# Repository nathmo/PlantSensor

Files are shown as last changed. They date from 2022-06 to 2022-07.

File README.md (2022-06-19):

# PlantSensor
Sensors node to monitor ambient light, temperature, humitidy, noise and soil moisture.
It it also able to drive a water pump and two light and have a LoRa transceiver to hopefully prevent my house plants from dying (among other use)
it was designed with a few use case in mind : indoor plant, outdoor plant, weather station, mailbox notifier, environemental sensor (3 I2C port that can be used for with sensors @ 3V3)
it is low power (when en deepsleep) (current draw under 50 uA@3V7 and even less at 12V)

## Features
- 3 I2C port for 3V3 peripheral (designed for OLED display, lux meter, pressure sensors)
- ambiant humidity sensors and temperature (DHT11)
- soil humidity sensors (capacitive module with analog out)
- lux meter
- pressure sensor
- microhone (detect noise level + weather / rain / wind ?)
- 3 mosftet output, max 6A total accross 3 mosfet at any time
- low power features, turn off every peripheral except ESP32 that can deepsleep and LoRa
- LoRa (433Mhz) (not compatible with TTN :( 868 Mhz is too expensive) , wifi and bluetooth connectivity
- buzzer to locate the sensors (and maybe repell some animal ?)
- GPS to track the sensors and have an accurate time base
- local data display on OLED screen or remote via the LoRa
- input voltage monitoring, get an idea of the battery left if powered by one

PCBB
PCBA

the PCB is 70 mm * 70 mm, i will add a better fixation system

## content
kicad schematic
BOM (20-40 CHF per unit, aliexpress as sole suplier (except PCB itself)

## futur works
- assemble and test the PCB once its manufactured
- write code to use it
- check current of the buck converter in low power mode

## firmware 
whenever the CPU come out of the sleep mode one of the following action should be performed :

mode 1)
read the config
read the sensors specified in the config
take the decision to turn on or off the mosfet if the condition set in the config are set
take the decision to display the data as specified in the config
send the data to a server if set in the config
retreive config update from the server if any and update own config or pass it to the next node

mode 2)
just transmit to any exit node the data passed uppon
applie the insctruction if we are the destination node

comming out of sleep mode are set in the config
- button action
- timer
- LoRa event

which system they trigger should also be specified in the config

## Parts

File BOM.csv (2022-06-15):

screw terminal | https://fr.aliexpress.com/item/4000290521933.html
mosfet | https://fr.aliexpress.com/item/32902232749.html
buck | https://fr.aliexpress.com/item/4000714041437.html
buzzer | https://fr.aliexpress.com/item/32857436073.html
microphone | https://fr.aliexpress.com/item/4000964400783.html
luxmeter | https://fr.aliexpress.com/item/32859303675.html
pressure | https://fr.aliexpress.com/item/1005001827073707.html
switch | https://fr.aliexpress.com/item/1005001291454145.html
LoRa 433 | https://fr.aliexpress.com/item/1005003451087717.html
GPS | https://fr.aliexpress.com/item/1005001704030454.html
screen | https://fr.aliexpress.com/item/32777216785.html
ESP32 | https://fr.aliexpress.com/item/32813525150.html
soil moisture | https://fr.aliexpress.com/item/32908693444.html
air moisture | https://fr.aliexpress.com/item/1005003157663107.html
DIODE | https://fr.aliexpress.com/item/1005003367932203.html

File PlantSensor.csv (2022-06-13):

Source: | /home/nathann/OneDrive/Documents/Projet/electronic/PlantSensor/PlantSensor/PlantSensor.kicad_sch
Date: | lun 13 jun 2022 01:12:29
Tool: | Eeschema 6.0.2+dfsg-1
Generator: | /usr/share/kicad/plugins/bom_csv_grouped_by_value.py
Component Count: | 51
Individual Components:
Item | Qty | Reference(s) | Value | LibPart | Footprint | Datasheet | MPN | SKU
 |  | BZ1 | Buzzer | Device:Buzzer | Buzzer_Beeper:Buzzer_12x9.5RM7.6 | ~
 |  | C1 | 10uF | Device:C | Capacitor_SMD:C_1206_3216Metric | ~
 |  | C2 | 10uF | Device:C | Capacitor_SMD:C_1206_3216Metric | ~
 |  | C3 | 100nF | Device:C | Capacitor_SMD:C_1206_3216Metric | ~
 |  | C4 | 10uF | Device:C | Capacitor_SMD:C_1206_3216Metric | ~
 |  | C5 | 10uF | Device:C | Capacitor_SMD:C_1206_3216Metric | ~
 |  | C6 | 10uF | Device:C | Capacitor_SMD:C_1206_3216Metric | ~
 |  | C7 | 100nF | Device:C | Capacitor_SMD:C_1206_3216Metric | ~
 |  | C8 | 100nF | Device:C | Capacitor_SMD:C_1206_3216Metric | ~
 |  | C9 | 100nF | Device:C | Capacitor_SMD:C_1206_3216Metric | ~
 |  | C10 | 100nF | Device:C | Capacitor_SMD:C_1206_3216Metric | ~
 |  | C11 | 100nF | Device:C | Capacitor_SMD:C_1206_3216Metric | ~
 |  | C12 | 100nF | Device:C | Capacitor_SMD:C_1206_3216Metric | ~
 |  | C13 | 100nF | Device:C | Capacitor_SMD:C_1206_3216Metric | ~
 |  | C14 | 100nF | Device:C | Capacitor_SMD:C_1206_3216Metric | ~
 |  | J1 | SCREW-TERMINAL-GREEN_2P-5.0_ | OPL_Connector:SCREW-TERMINAL-GREEN_2P-5.0_ | OPL_Connector:H2-5.0-10.5X8.0MM |  |  | 320110031
 |  | J2 | SCREW-TERMINAL-GREEN_2P-5.0_ | OPL_Connector:SCREW-TERMINAL-GREEN_2P-5.0_ | OPL_Connector:H2-5.0-10.5X8.0MM |  |  | 320110031
 |  | J3 | SCREW-TERMINAL-GREEN_2P-5.0_ | OPL_Connector:SCREW-TERMINAL-GREEN_2P-5.0_ | OPL_Connector:H2-5.0-10.5X8.0MM |  |  | 320110031
 |  | J4 | SCREW-TERMINAL-GREEN_2P-5.0_ | OPL_Connector:SCREW-TERMINAL-GREEN_2P-5.0_ | OPL_Connector:H2-5.0-10.5X8.0MM |  |  | 320110031
 |  | J5 | DIP-BLACK-MALE-HEADER-VERT_2P-2.54_ | OPL_Connector:DIP-BLACK-MALE-HEADER-VERT_2P-2.54_ | OPL_Connector:H2-2.54 |  | P125-1102A0BS116A1 | 320020016
 |  | J6 | DIP-BLACK-MALE-HEADER-VERT_4P-2.54_ | OPL_Connector:DIP-BLACK-MALE-HEADER-VERT_4P-2.54_ | OPL_Connector:H4-2.54 |  | P125-1104A0BS116A1 | 320020017
 |  | Q1 | N-Channel_30-V_MOSFET | PlantSensorsComponents:N-Channel_30-V_MOSFET | Package_TO_SOT_SMD:TO-252-2
 |  | Q2 | N-Channel_30-V_MOSFET | PlantSensorsComponents:N-Channel_30-V_MOSFET | Package_TO_SOT_SMD:TO-252-2
 |  | Q3 | N-Channel_30-V_MOSFET | PlantSensorsComponents:N-Channel_30-V_MOSFET | Package_TO_SOT_SMD:TO-252-2
 |  | Q4 | N-Channel_30-V_MOSFET | PlantSensorsComponents:N-Channel_30-V_MOSFET | Package_TO_SOT_SMD:TO-252-2
 |  | R1 | 1K | Device:R | Resistor_SMD:R_1206_3216Metric | ~
 |  | R2 | 10K | Device:R | Resistor_SMD:R_1206_3216Metric | ~
 |  | R3 | 10K | Device:R | Resistor_SMD:R_1206_3216Metric | ~
 |  | R4 | 10K | Device:R | Resistor_SMD:R_1206_3216Metric | ~
 |  | R5 | 10K | Device:R | Resistor_SMD:R_1206_3216Metric | ~
 |  | R6 | 10R | Device:R | Resistor_SMD:R_1206_3216Metric | ~
 |  | R7 | 10R | Device:R | Resistor_SMD:R_1206_3216Metric | ~
 |  | R8 | 10R | Device:R | Resistor_SMD:R_1206_3216Metric | ~
 |  | R9 | 10R | Device:R | Resistor_SMD:R_1206_3216Metric | ~
 |  | R10 | 1K | Device:R | Resistor_SMD:R_1206_3216Metric | ~
 |  | R11 | 1K | Device:R | Resistor_SMD:R_1206_3216Metric | ~
 |  | R12 | 1M | Device:R | Resistor_SMD:R_1206_3216Metric | ~
 |  | R13 | 100K | Device:R | Resistor_SMD:R_1206_3216Metric | ~
 |  | SW1 | SW_Reed | Switch:SW_Reed | Resistor_THT:R_Axial_DIN0207_L6.3mm_D2.5mm_P10.16mm_Horizontal | ~
 |  | SW2 | SW_Reed | Switch:SW_Reed | Resistor_THT:R_Axial_DIN0207_L6.3mm_D2.5mm_P10.16mm_Horizontal | ~
 |  | U1 | BuckConverter | PlantSensorsComponents:BuckConverter | PlantSensor:Buck
 |  | U2 | MIC5219-3.3YM5 | Regulator_Linear:MIC5219-3.3YM5 | Package_TO_SOT_SMD:SOT-23-5 | http://ww1.microchip.com/downloads/en/DeviceDoc/MIC5219-500mA-Peak-Output-LDO-Regulator-DS20006021A.pdf
 |  | U3 | ESP32-WROOM-32 | RF_Module:ESP32-WROOM-32 | RF_Module:ESP32-WROOM-32 | https://www.espressif.com/sites/default/files/documentation/esp32-wroom-32_datasheet_en.pdf
 |  | U4 | XL1278-SMT | Misc RF:XL1278-SMT | Misc RF:XL1278-SMT
 |  | U5 | I2C_Display | PlantSensorsComponents:I2C_Display | PlantSensor:Display
 |  | U6 | BMP280Module | PlantSensorsComponents:BMP280Module | PlantSensor:BMP280Module
 |  | U7 | GY-302_BH1750 | PlantSensorsComponents:GY-302_BH1750 | PlantSensor:BH1750
 |  | U8 | GPS_NEO-M8N_module | PlantSensorsComponents:GPS_NEO-M8N_module | PlantSensor:GPS
 |  | U9 | SPH0645Module | PlantSensorsComponents:SPH0645Module | PlantSensor:MicrophoneSPH0645
 |  | U10 | Capacitive_Soil_Moisture | PlantSensorsComponents:Capacitive_Soil_Moisture | OPL_Connector:H3-2.54
 |  | U11 | TEM-HUM-DHT11_4P-15.5X12.0MM_ | OPL_Sensor-Transducer:TEM-HUM-DHT11_4P-15.5X12.0MM_ | OPL_Sensor-Transducer:SNR4-2.54-15.5X12.0X5.5MM |  | DHT11 | 314010000
Collated Components:
Item | Qty | Reference(s) | Value | LibPart | Footprint | Datasheet | MPN | SKU
1 | 1 | BZ1 | Buzzer | Device:Buzzer | Buzzer_Beeper:Buzzer_12x9.5RM7.6 | ~
2 | 5 | C1, C2, C4, C5, C6 | 10uF | Device:C | Capacitor_SMD:C_1206_3216Metric | ~
3 | 9 | C3, C7, C8, C9, C10, C11, C12, C13, C14 | 100nF | Device:C | Capacitor_SMD:C_1206_3216Metric | ~
4 | 4 | J1, J2, J3, J4 | SCREW-TERMINAL-GREEN_2P-5.0_ | OPL_Connector:SCREW-TERMINAL-GREEN_2P-5.0_ | OPL_Connector:H2-5.0-10.5X8.0MM |  |  | 320110031
5 | 1 | J5 | DIP-BLACK-MALE-HEADER-VERT_2P-2.54_ | OPL_Connector:DIP-BLACK-MALE-HEADER-VERT_2P-2.54_ | OPL_Connector:H2-2.54 |  | P125-1102A0BS116A1 | 320020016
6 | 1 | J6 | DIP-BLACK-MALE-HEADER-VERT_4P-2.54_ | OPL_Connector:DIP-BLACK-MALE-HEADER-VERT_4P-2.54_ | OPL_Connector:H4-2.54 |  | P125-1104A0BS116A1 | 320020017
7 | 4 | Q1, Q2, Q3, Q4 | N-Channel_30-V_MOSFET | PlantSensorsComponents:N-Channel_30-V_MOSFET | Package_TO_SOT_SMD:TO-252-2
8 | 3 | R1, R10, R11 | 1K | Device:R | Resistor_SMD:R_1206_3216Metric | ~
9 | 4 | R2, R3, R4, R5 | 10K | Device:R | Resistor_SMD:R_1206_3216Metric | ~
10 | 4 | R6, R7, R8, R9 | 10R | Device:R | Resistor_SMD:R_1206_3216Metric | ~
11 | 1 | R12 | 1M | Device:R | Resistor_SMD:R_1206_3216Metric | ~
12 | 1 | R13 | 100K | Device:R | Resistor_SMD:R_1206_3216Metric | ~
13 | 2 | SW1, SW2 | SW_Reed | Switch:SW_Reed | Resistor_THT:R_Axial_DIN0207_L6.3mm_D2.5mm_P10.16mm_Horizontal | ~
14 | 1 | U1 | BuckConverter | PlantSensorsComponents:BuckConverter | PlantSensor:Buck
15 | 1 | U2 | MIC5219-3.3YM5 | Regulator_Linear:MIC5219-3.3YM5 | Package_TO_SOT_SMD:SOT-23-5 | http://ww1.microchip.com/downloads/en/DeviceDoc/MIC5219-500mA-Peak-Output-LDO-Regulator-DS20006021A.pdf
16 | 1 | U3 | ESP32-WROOM-32 | RF_Module:ESP32-WROOM-32 | RF_Module:ESP32-WROOM-32 | https://www.espressif.com/sites/default/files/documentation/esp32-wroom-32_datasheet_en.pdf
17 | 1 | U4 | XL1278-SMT | Misc RF:XL1278-SMT | Misc RF:XL1278-SMT
18 | 1 | U5 | I2C_Display | PlantSensorsComponents:I2C_Display | PlantSensor:Display
19 | 1 | U6 | BMP280Module | PlantSensorsComponents:BMP280Module | PlantSensor:BMP280Module
20 | 1 | U7 | GY-302_BH1750 | PlantSensorsComponents:GY-302_BH1750 | PlantSensor:BH1750
21 | 1 | U8 | GPS_NEO-M8N_module | PlantSensorsComponents:GPS_NEO-M8N_module | PlantSensor:GPS
22 | 1 | U9 | SPH0645Module | PlantSensorsComponents:SPH0645Module | PlantSensor:MicrophoneSPH0645
23 | 1 | U10 | Capacitive_Soil_Moisture | PlantSensorsComponents:Capacitive_Soil_Moisture | OPL_Connector:H3-2.54
24 | 1 | U11 | TEM-HUM-DHT11_4P-15.5X12.0MM_ | OPL_Sensor-Transducer:TEM-HUM-DHT11_4P-15.5X12.0MM_ | OPL_Sensor-Transducer:SNR4-2.54-15.5X12.0X5.5MM |  | DHT11 | 314010000

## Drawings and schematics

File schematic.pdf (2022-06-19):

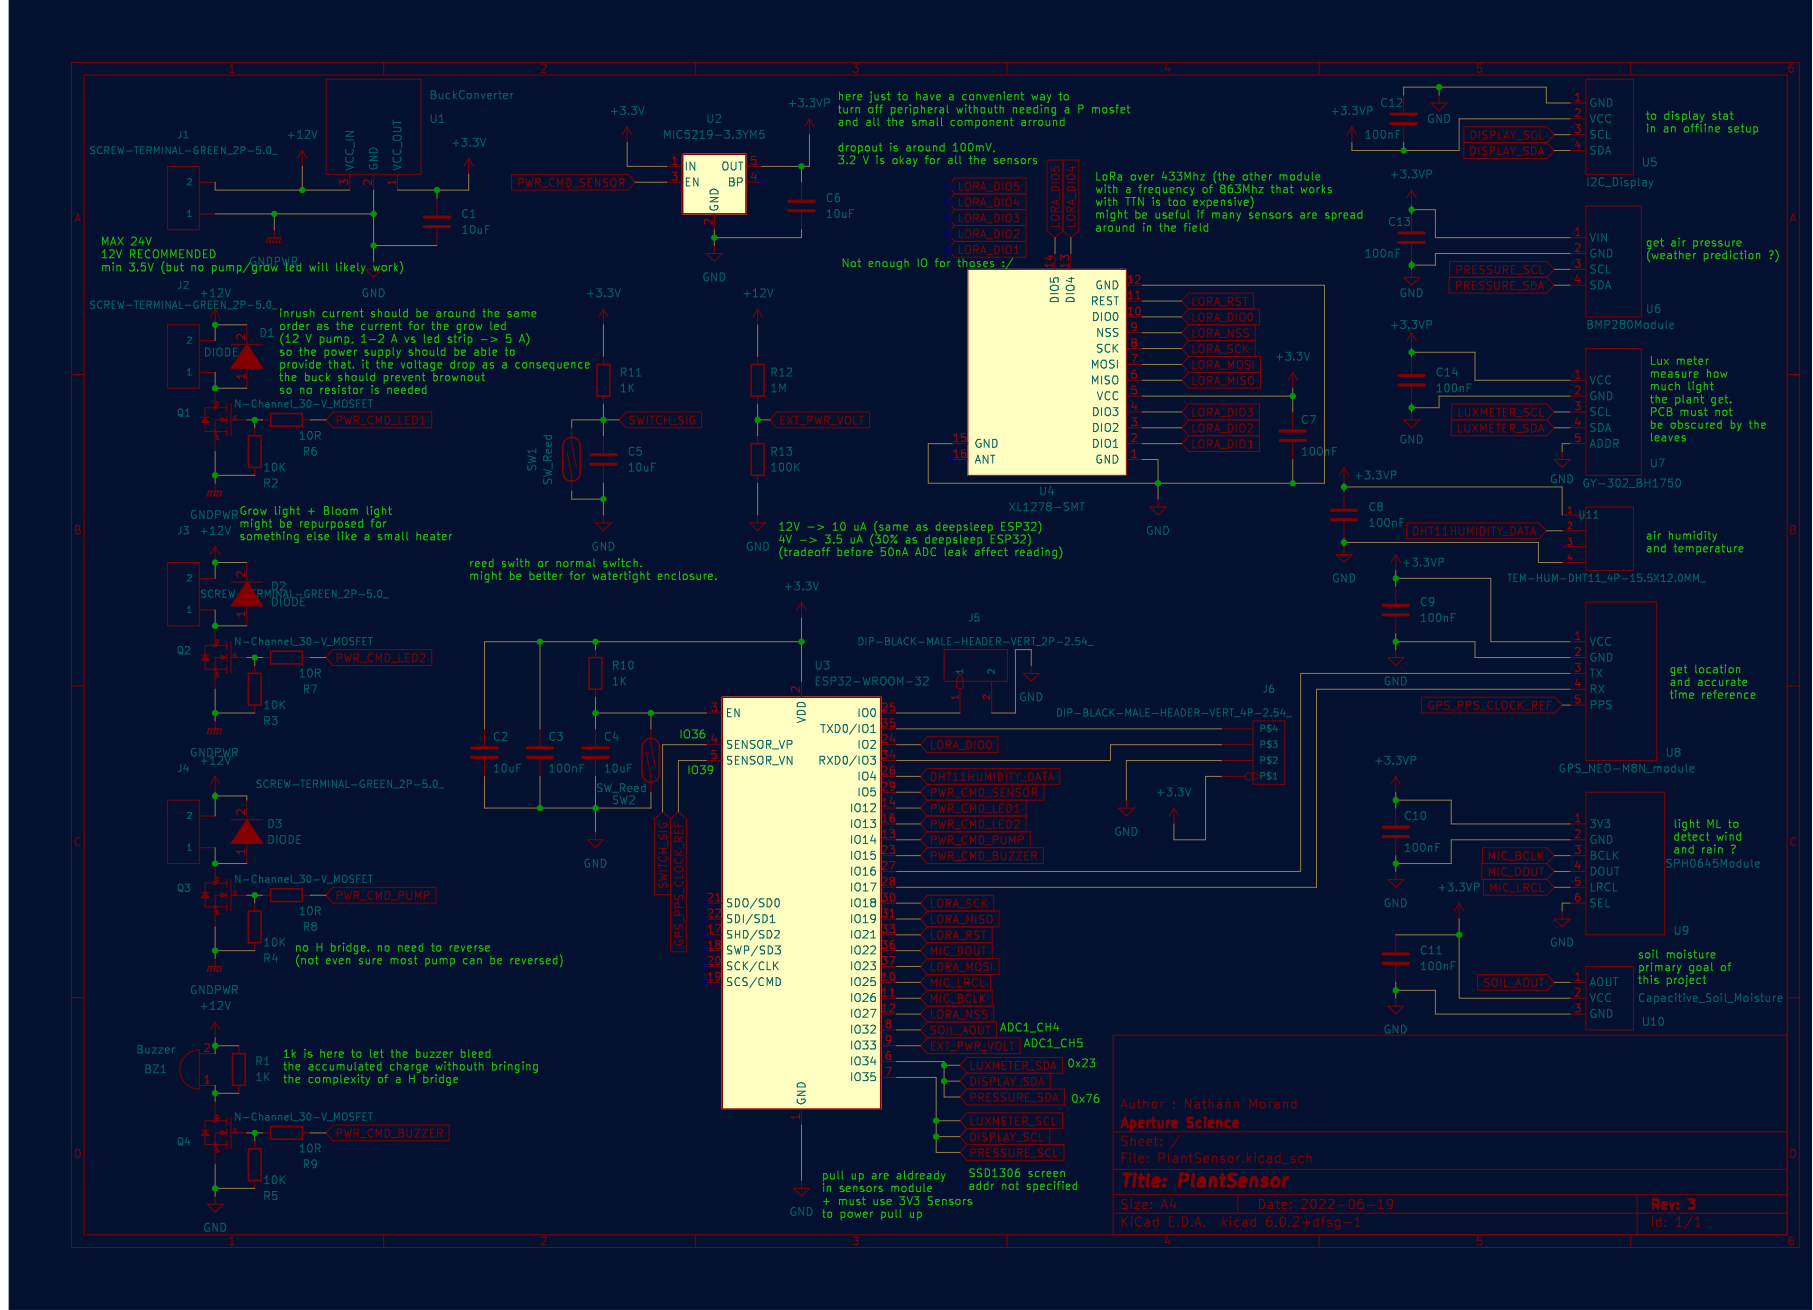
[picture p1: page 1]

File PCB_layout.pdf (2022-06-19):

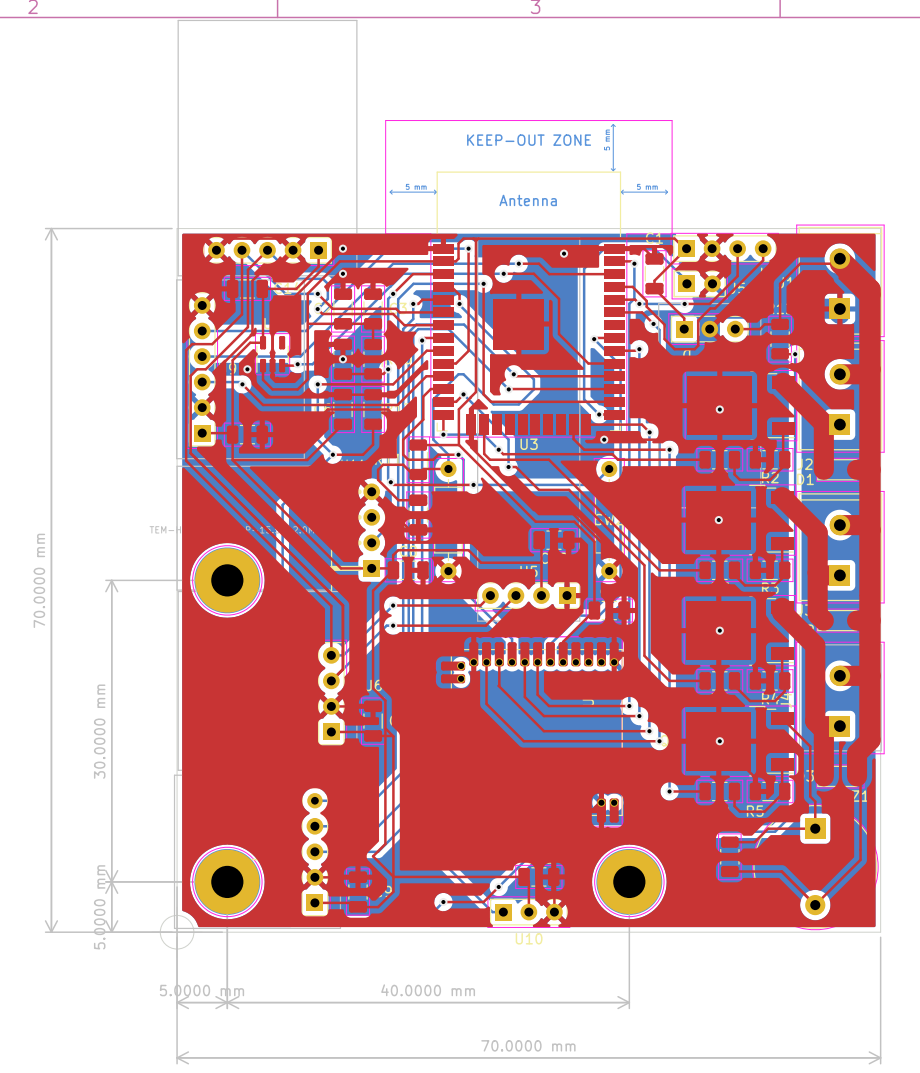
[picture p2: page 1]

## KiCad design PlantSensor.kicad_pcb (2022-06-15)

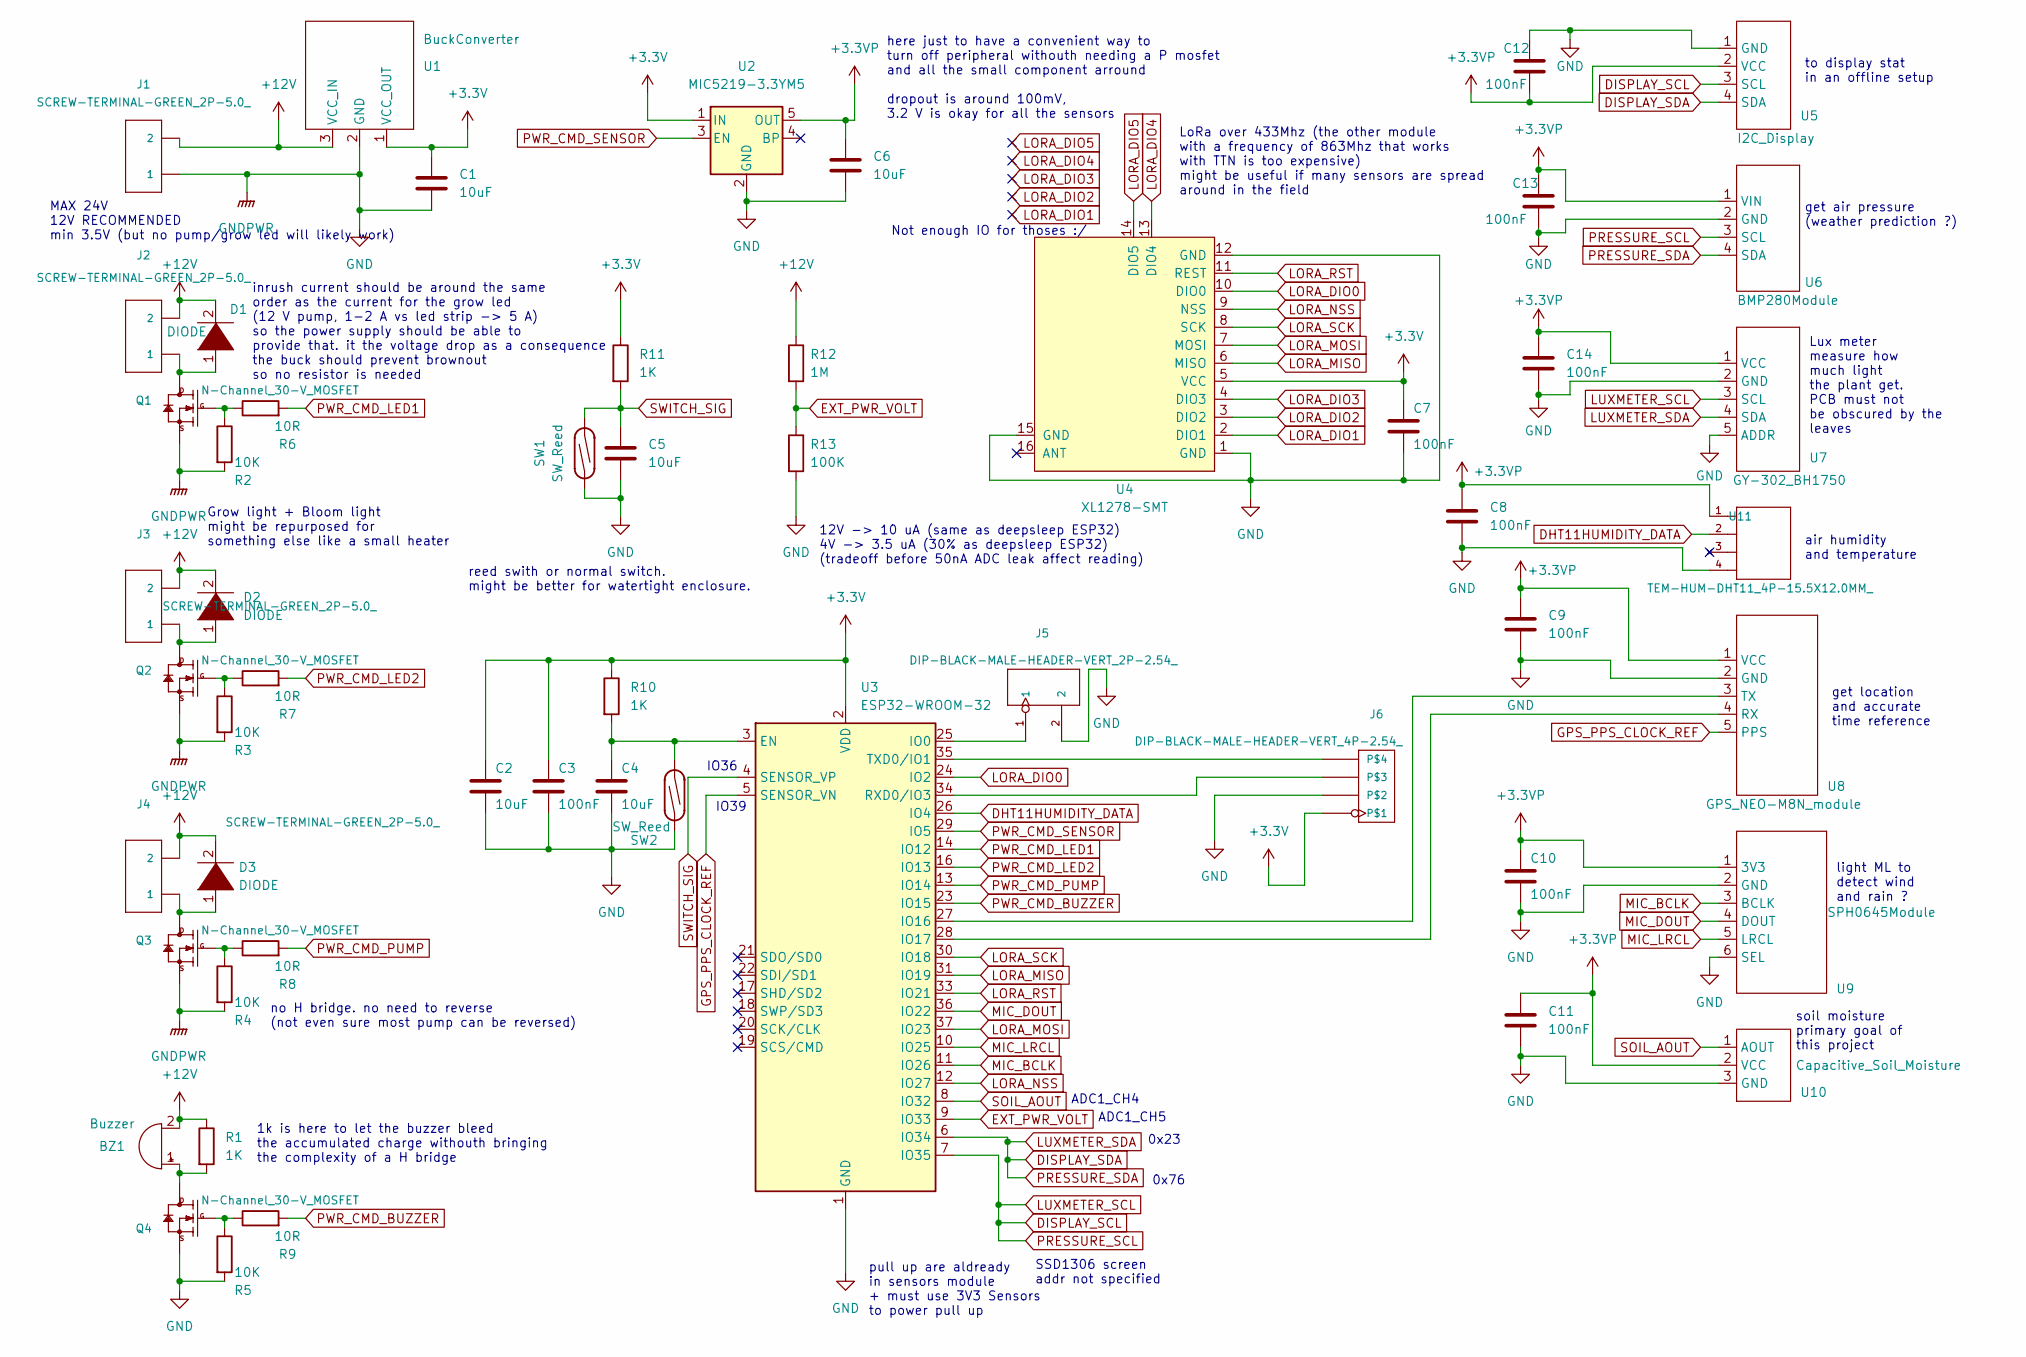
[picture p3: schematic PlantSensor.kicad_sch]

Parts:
BZ1: Buzzer; Buzzer_12x9.5RM7.6
C1, C2, C4, C5, C6: 10uF; C_1206_3216Metric
C3, C7, C8, C9, C10, C11, C12, C13, C14: 100nF; C_1206_3216Metric
D1, D2, D3: DIODE; D_SOD-123
J1, J2, J3, J4: SCREW-TERMINAL-GREEN_2P-5.0_; H2-5.0-10.5X8.0MM
J5: DIP-BLACK-MALE-HEADER-VERT_2P-2.54_; H2-2.54; MPN P125-1102A0BS116A1
J6: DIP-BLACK-MALE-HEADER-VERT_4P-2.54_; H4-2.54; MPN P125-1104A0BS116A1
Q1, Q2, Q3, Q4: N-Channel_30-V_MOSFET; TO-252-2
R1, R10, R11: 1K; R_1206_3216Metric
R2, R3, R4, R5: 10K; R_1206_3216Metric
R6, R7, R8, R9: 10R; R_1206_3216Metric
R12: 1M; R_1206_3216Metric
R13: 100K; R_1206_3216Metric
SW1, SW2: SW_Reed; R_Axial_DIN0207_L6.3mm_D2.5mm_P10.16mm_Horizontal
U1: BuckConverter; Buck
U2: MIC5219-3.3YM5; SOT-23-5
U3: ESP32-WROOM-32
U4: XL1278-SMT
U5: I2C_Display; Display
U6: BMP280Module
U7: GY-302_BH1750; BH1750
U8: GPS_NEO-M8N_module; GPS
U9: SPH0645Module; MicrophoneSPH0645
U10: Capacitive_Soil_Moisture; H3-2.54
U11: TEM-HUM-DHT11_4P-15.5X12.0MM_; SNR4-2.54-15.5X12.0X5.5MM; MPN DHT11

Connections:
+3.3VP: C6.1, C8.1, C9.1, C10.1, C11.1, C12.2, C13.1, C14.1, U2.5 (OUT), U5.2 (VCC), U6.1 (VIN), U7.1 (VCC), U8.1 (VCC), U9.1 (3V3), U10.2 (VCC), U11.1 (VDD)
+3V3: C1.1, C2.1, C3.1, C7.1, J6.1, R10.1, R11.1, U1.1 (VCC_OUT), U2.1 (IN), U3.2 (VDD), U4.5 (VCC)
+12V: BZ1.2 (+), D1.2 (A), D2.2 (A), D3.2 (A), J1.2, J2.2, J3.2, J4.2, R1.1, R12.1, U1.3 (VCC_IN)
DHT11HUMIDITY_DATA: U3.26 (IO4), U11.2 (DATA)
DISPLAY_SCL: U3.7 (IO35), U5.3 (SCL), U6.3 (SCL), U7.3 (SCL)
DISPLAY_SDA: U3.6 (IO34), U5.4 (SDA), U6.4 (SDA), U7.4 (SDA)
EXT_PWR_VOLT: R12.2, R13.1, U3.9 (IO33)
GND: C1.2, C2.2, C3.2, C4.2, C5.2, C6.2, C7.2, C8.2, C9.2, C10.2, C11.2, C12.1, C13.2, C14.2, J1.1, J5.2, J6.2, Q1.2 (S), Q2.2 (S), Q3.2 (S), Q4.2 (S), R2.2, R3.2, R4.2, R5.2, R13.2, SW1.1, SW2.1, U1.2 (GND), U2.2 (GND), U3.1 (GND), U3.15 (GND), U3.38 (GND), U3.39 (GND), U4.1 (GND), U4.12 (GND), U4.15 (GND), U5.1 (GND), U6.2 (GND), U7.2 (GND), U7.5 (ADDR), U8.2 (GND), U9.2 (GND), U9.6 (SEL), U10.3 (GND), U11.4 (GND)
GPS_PPS_CLOCK_REF: U3.5 (SENSOR_VN), U8.5 (PPS)
LORA_DIO0: U3.24 (IO2), U4.10 (DIO0)
LORA_DIO1: U4.2 (DIO1)
LORA_DIO2: U4.3 (DIO2)
LORA_DIO3: U4.4 (DIO3)
LORA_DIO4: U4.13 (DIO4)
LORA_DIO5: U4.14 (DIO5)
LORA_MISO: U3.31 (IO19), U4.6 (MISO)
LORA_MOSI: U3.37 (IO23), U4.7 (MOSI)
LORA_NSS: U3.12 (IO27), U4.9 (NSS)
LORA_RST: U3.33 (IO21), U4.11 (REST)
LORA_SCK: U3.30 (IO18), U4.8 (SCK)
MIC_BCLK: U3.11 (IO26), U9.3 (BCLK)
MIC_DOUT: U3.36 (IO22), U9.4 (DOUT)
MIC_LRCL: U3.10 (IO25), U9.5 (LRCL)
unnamed: BZ1.1 (-), Q4.3 (D), R1.2
unnamed: C4.1, R10.2, SW2.2, U3.3 (EN)
unnamed: D1.1 (K), J2.1, Q1.3 (D)
unnamed: D2.1 (K), J3.1, Q2.3 (D)
unnamed: D3.1 (K), J4.1, Q3.3 (D)
unnamed: J5.1, U3.25 (IO0)
unnamed: J6.3, U3.34 (RXD0/IO3)
unnamed: J6.4, U3.35 (TXD0/IO1)
unnamed: Q1.1 (G), R2.1, R6.1
unnamed: Q2.1 (G), R3.1, R7.1
unnamed: Q3.1 (G), R4.1, R8.1
unnamed: Q4.1 (G), R5.1, R9.1
unnamed: U3.27 (IO16), U8.3 (TX)
unnamed: U3.28 (IO17), U8.4 (RX)
PWR_CMD_BUZZER: R9.2, U3.23 (IO15)
PWR_CMD_LED1: R6.2, U3.14 (IO12)
PWR_CMD_LED2: R7.2, U3.16 (IO13)
PWR_CMD_PUMP: R8.2, U3.13 (IO14)
PWR_CMD_SENSOR: U2.3 (EN), U3.29 (IO5)
SOIL_AOUT: U3.8 (IO32), U10.1 (AOUT)
SWITCH_SIG: C5.1, R11.2, SW1.2, U3.4 (SENSOR_VP)

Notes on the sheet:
Not enough IO for thoses :/
Grow light + Bloom light might be repurposed for something else like a small heater
to display stat in an offline setup
air humidity and temperature
IO39
MAX 24V 12V RECOMMENDED min 3.5V (but no pump/grow led will likely work)
no H bridge. no need to reverse (not even sure most pump can be reversed)
light ML to detect wind and rain ?
LoRa over 433Mhz (the other module with a frequency of 863Mhz that works with TTN is too expensive) might be useful if many sensors are spread around in the field
soil moisture primary goal of this project
inrush current should be around the same order as the current for the grow led (12 V pump, 1-2 A vs led strip -> 5 A) so the power supply should be able to provide that. it the voltage drop as a consequence the buck should prevent brownout so no resistor is needed
Lux meter measure how much light the plant get. PCB must not be obscured by the leaves
0x76
here just to have a convenient way to turn off peripheral withouth needing a P mosfet and all the small component arround dropout is around 100mV, 3.2 V is okay for all the sensors
reed swith or normal switch. might be better for watertight enclosure.
get location and accurate time reference
1k is here to let the buzzer bleed the accumulated charge withouth bringing the complexity of a H bridge
12V -> 10 uA (same as deepsleep ESP32) 4V -> 3.5 uA (30% as deepsleep ESP32) (tradeoff before 50nA ADC leak affect reading)
ADC1_CH5
ADC1_CH4
0x23
get air pressure (weather prediction ?)
SSD1306 screen addr not specified
pull up are aldready in sensors module + must use 3V3 Sensors to power pull up
IO36

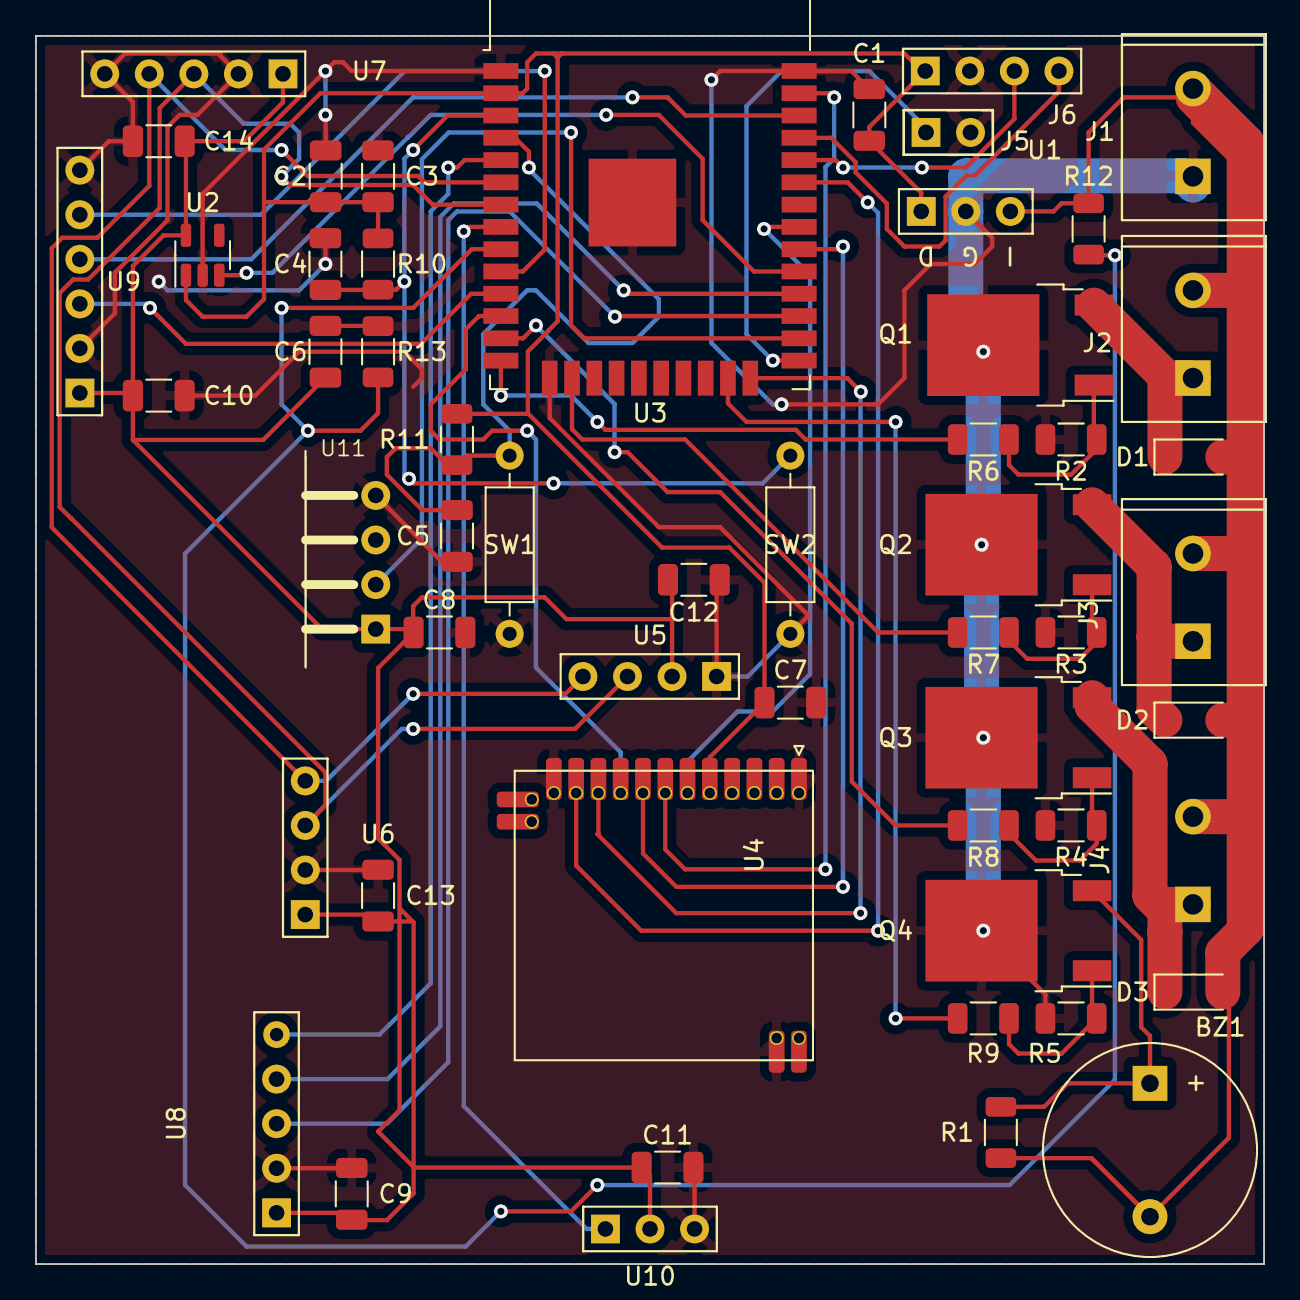
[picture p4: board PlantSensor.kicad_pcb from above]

Board: 2 copper layers, 70.0 x 70.0 mm, 54 parts (0 on the bottom side), 39 nets.

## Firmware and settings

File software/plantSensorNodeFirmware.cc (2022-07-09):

#include <WiFi.h>
#include <ESPAsyncWebServer.h>
#include <ESPDash.h>
#include <json.hpp>
#include <map>   
#include <ESPmDNS.h>
#include <HTTPClient.h>
#include <Ticker.h>
#include <DHTesp.h>
 
const char* ssid = "SSID";
const char* password =  "PASSWORD";
 
const char * host =  "plantSensor00";
IPAddress serverIp;
const int measurementIntervalMs = 20000;

const int sensorPin = 17;
DHTesp dht;


AsyncWebServer server(80);
ESPDash dashboard(&server); 
 
std::map<std::string, Card> sensorCards;
 
void connectWiFi(){
 
  WiFi.begin(ssid, password); 
  
  while (WiFi.status() != WL_CONNECTED) { 
    delay(1000);
    Serial.println("Connecting to WiFi..");
  }
 
  Serial.println("Connected to WiFi network");
}
 
void startMdns(){
   
  while(!MDNS.begin(host)) {
     Serial.println("Starting mDNS...");
     delay(1000);
  }
 
  Serial.println("MDNS started");
}
 
void resolveHostAddress(){
   
  while(mdns_init()!= ESP_OK){
    delay(1000);
    Serial.println("Starting MDNS...");
  }
 
  Serial.println("MDNS started");
 
  while (serverIp.toString() == "0.0.0.0") {
    Serial.println("Resolving host...");
    delay(250);
    serverIp = MDNS.queryHost(host);
  }
 
  Serial.println("Gateway address resolved");
}

void addCardIfNotExists(std::string id){
   
  if (sensorCards.find(id) == sensorCards.end()) {
 
    sensorCards.emplace(
      std::piecewise_construct,
      std::forward_as_tuple(id), 
      std::forward_as_tuple(&dashboard, TEMPERATURE_CARD, id.c_str(), "°C"));
  }
}

void postMeasurement() {
   
  float temp = dht.getTemperature();
 
  nlohmann::json measurement;  
  measurement["id"] = WiFi.macAddress().c_str();
  measurement["val"] = temp;
 
  std::string serializedObject = measurement.dump();
 
  HTTPClient http;   
  
  http.begin("http://" + serverIp.toString() + "/measurement");
  http.addHeader("Content-Type", "application/json");            
  
  int httpResponseCode = http.POST(serializedObject.c_str());
  
  Serial.println(httpResponseCode);
 
  http.end();
}
 
void updateCard(std::string id, float val){
  sensorCards.at(id).update(val);
  dashboard.sendUpdates();
}
 
void setup() {
  Serial.begin(115200);
  
  dht.setup(sensorPin, DHTesp::DHT22);
   
  connectWiFi();
  startMdns(); 
  resolveHostAddress();
  
  server.on(
    "/measurement",
    HTTP_POST,
    [](AsyncWebServerRequest * request){},
    NULL,
    [](AsyncWebServerRequest * request, uint8_t *data, size_t len, size_t index, size_t total) {
 
      nlohmann::json obj = nlohmann::json::parse(data, data+len);
 
      auto id = obj["id"].get<std::string>();
      auto val = obj["val"].get<float>();
 
      addCardIfNotExists(id);
      updateCard(id, val);
       
      request->send(200);          
  });
 
  server.begin();
  
  periodicTicker.attach_ms(measurementIntervalMs, postMeasurement);
}
  
void loop() {}

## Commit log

2022-06-15 fixed trace size + diode to prevent inductive load from damaging the mosfet
    [BOM.csv, PlantSensor.kicad_pcb, PlantSensor.kicad_sch]
2022-06-19 small improuvment
    added mounting hole
    improved silk screen
    generated gerber for manufacturing
    [PlantSensor-B_Cu.gbl, PlantSensor-B_Mask.gbs, PlantSensor-B_Paste.gbp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]
